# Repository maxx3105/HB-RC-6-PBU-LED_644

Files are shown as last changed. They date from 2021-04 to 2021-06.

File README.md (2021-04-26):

# HB-RC-6-PBU-LED_644
6-Fach Wandtaster mit Signal-Led auf Basis der AskSin++ für Homematic

Dieses Projekt basiert auf der Arbeit von [pa-pa](https://github.com/pa-pa/AskSinPP) ,[Jérôme](https://github.com/jp112sdl/Beispiel_AskSinPP).

# Hardware

### Bauteile

Bauteile                   | Bezeichnung          | Anzahl | Kommentar   | 
-------------------------- | -------------------- | ------ | ----------- | 
R1,R2                      | 240 Ohm              |   2    |             |
R3,R4                      | 10K Ohm              |   2    |             |
R5                         | 1K  Ohm              |   1    |             |
R6                         | 100K Ohm             |   1    |             |
C1, ..., C10               | 100n                 |   10   |             |
SW1, ..., SW7              | Taster               |   7    |             |
U1                         | Atmega 644P-AU       |   1    |             |
U2                         | CC1101               |   1    |             |
U3                         | SN74LVC1T45DBV       |   1    |             |
Q1                         | IRLML9301            |   1    |             |
D1                         | SMD Led 0805 Rot     |   1    |             |
D2                         | SMD Led 0805 Grün    |   1    |             |
D3,...,D8                  | SK6812 Mini          |   6    |             |
D9,...,D14                 | WS2812-2020          |   6    | Alternative |

Reichelt Liste comeing soon

#### Sonstiges

CC1101 https://de.aliexpress.com/item/32924239954.html

Taster https://de.aliexpress.com/item/32660690016.html?spm=a2g0s.9042311.0.0.27424c4dqj9wVN

~8,3 cm Draht als Antenne

### Programmieradapter

- 1x FTDI Programmer https://www.az-delivery.de/products/ftdi-adapter-ft232rl
- 1x ISP Programmer https://www.diamex.de/dxshop/USB-ISP-Programmer-fuer-Atmel-AVR

# Software

https://www.arduino.cc/en/software

### Firmware

Sketch https://github.com/jp112sdl/HB-RC-6-PBU-LED/blob/master/HB-RC-6-PBU-LED.ino

# Bauanleitung

coming soon

# Bilder
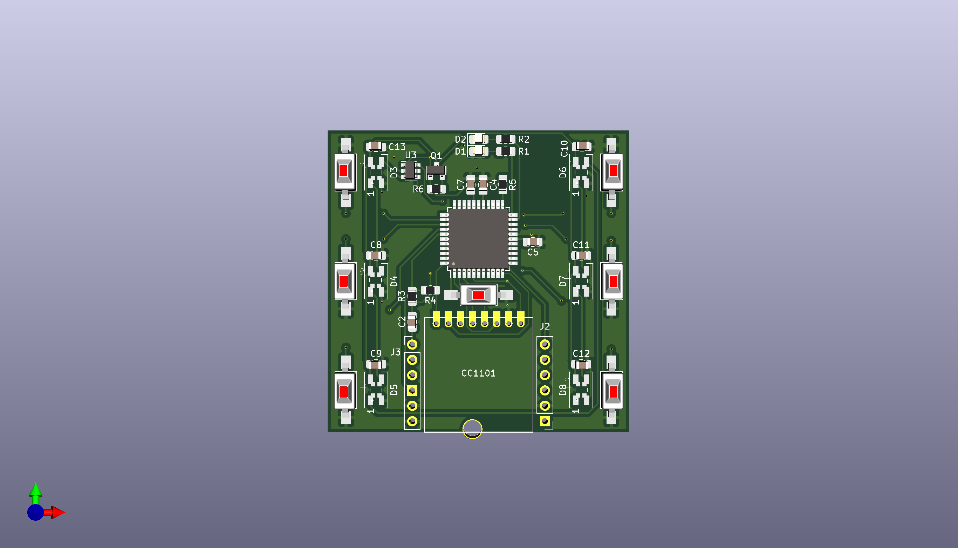
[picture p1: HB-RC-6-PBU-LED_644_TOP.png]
Vorderseite

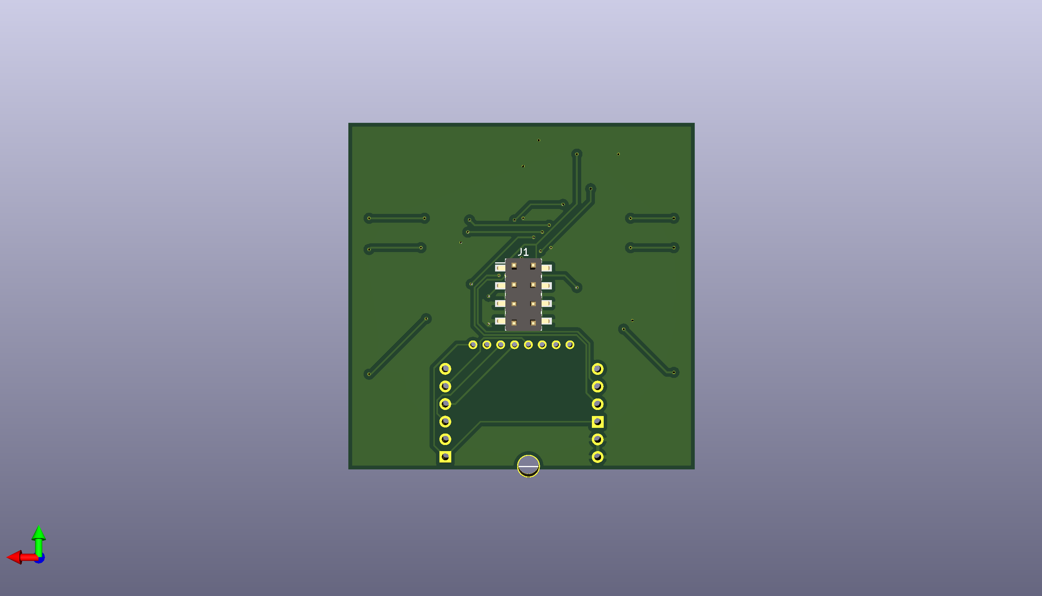
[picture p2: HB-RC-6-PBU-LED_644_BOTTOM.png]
Rückseite


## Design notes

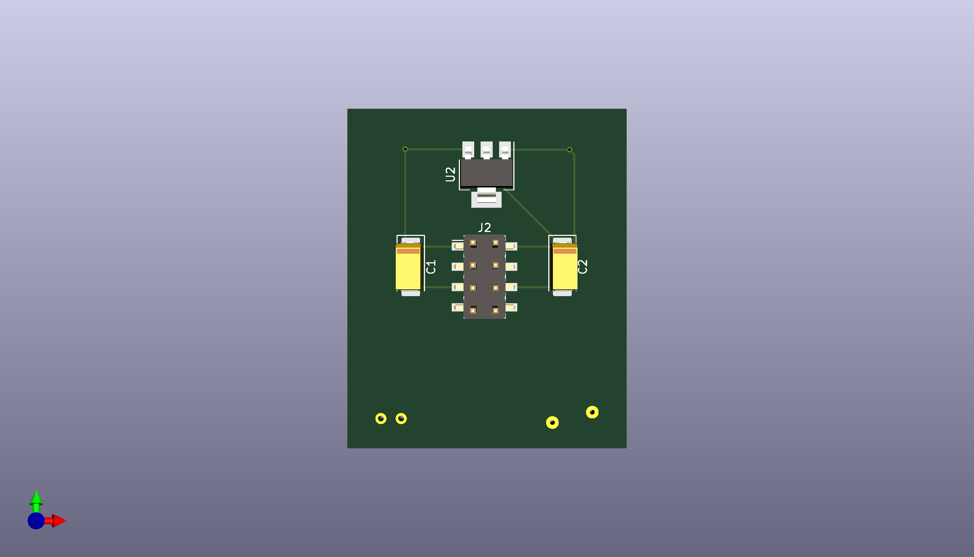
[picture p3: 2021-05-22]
Netzteil/Netzteil_Bottom.png

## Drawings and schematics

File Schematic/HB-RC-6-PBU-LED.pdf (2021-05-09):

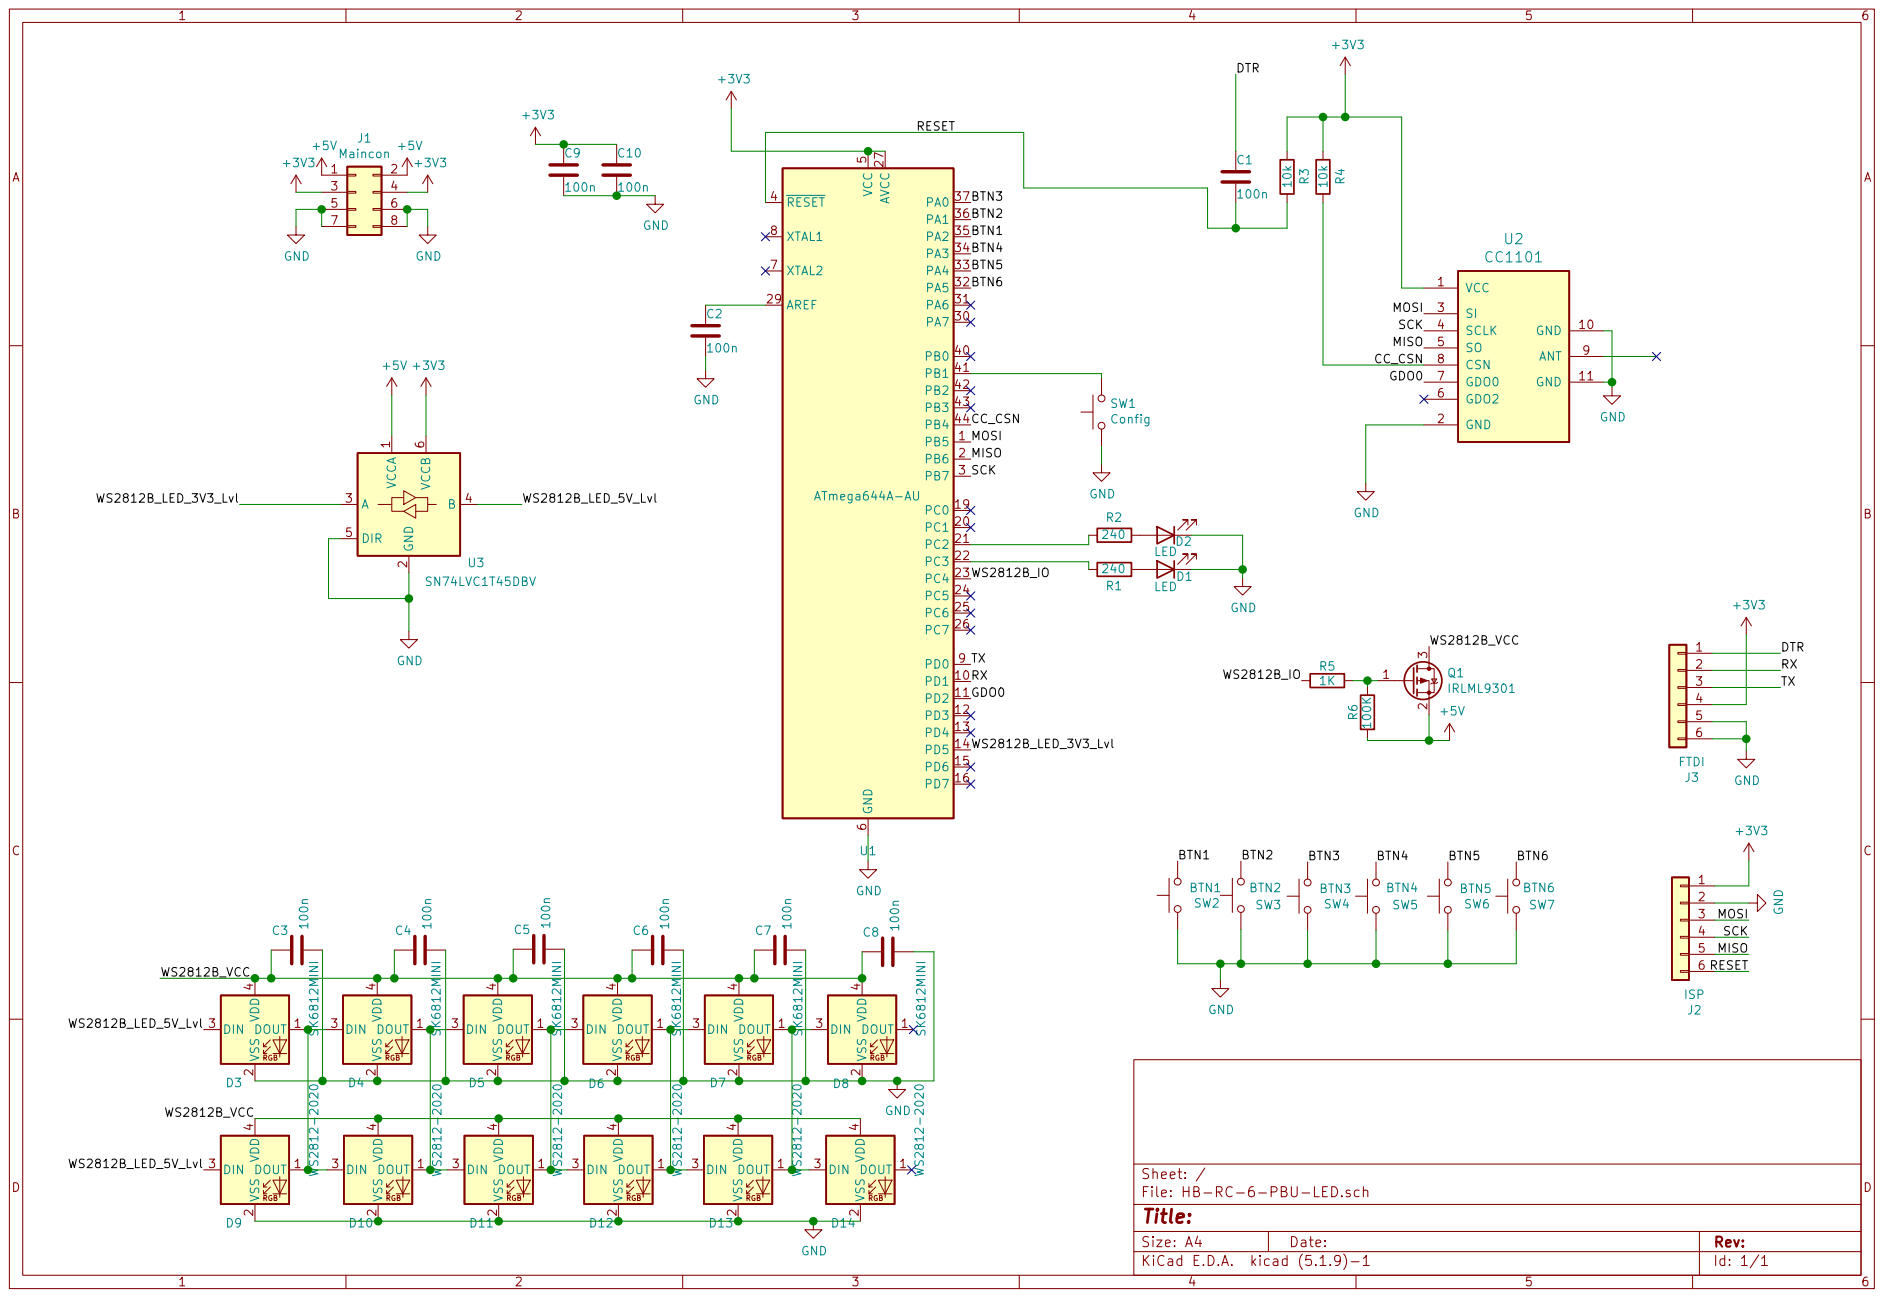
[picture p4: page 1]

Id: 1/1 Title: File: HB-RC-6-PBU-LED.sch Sheet: /

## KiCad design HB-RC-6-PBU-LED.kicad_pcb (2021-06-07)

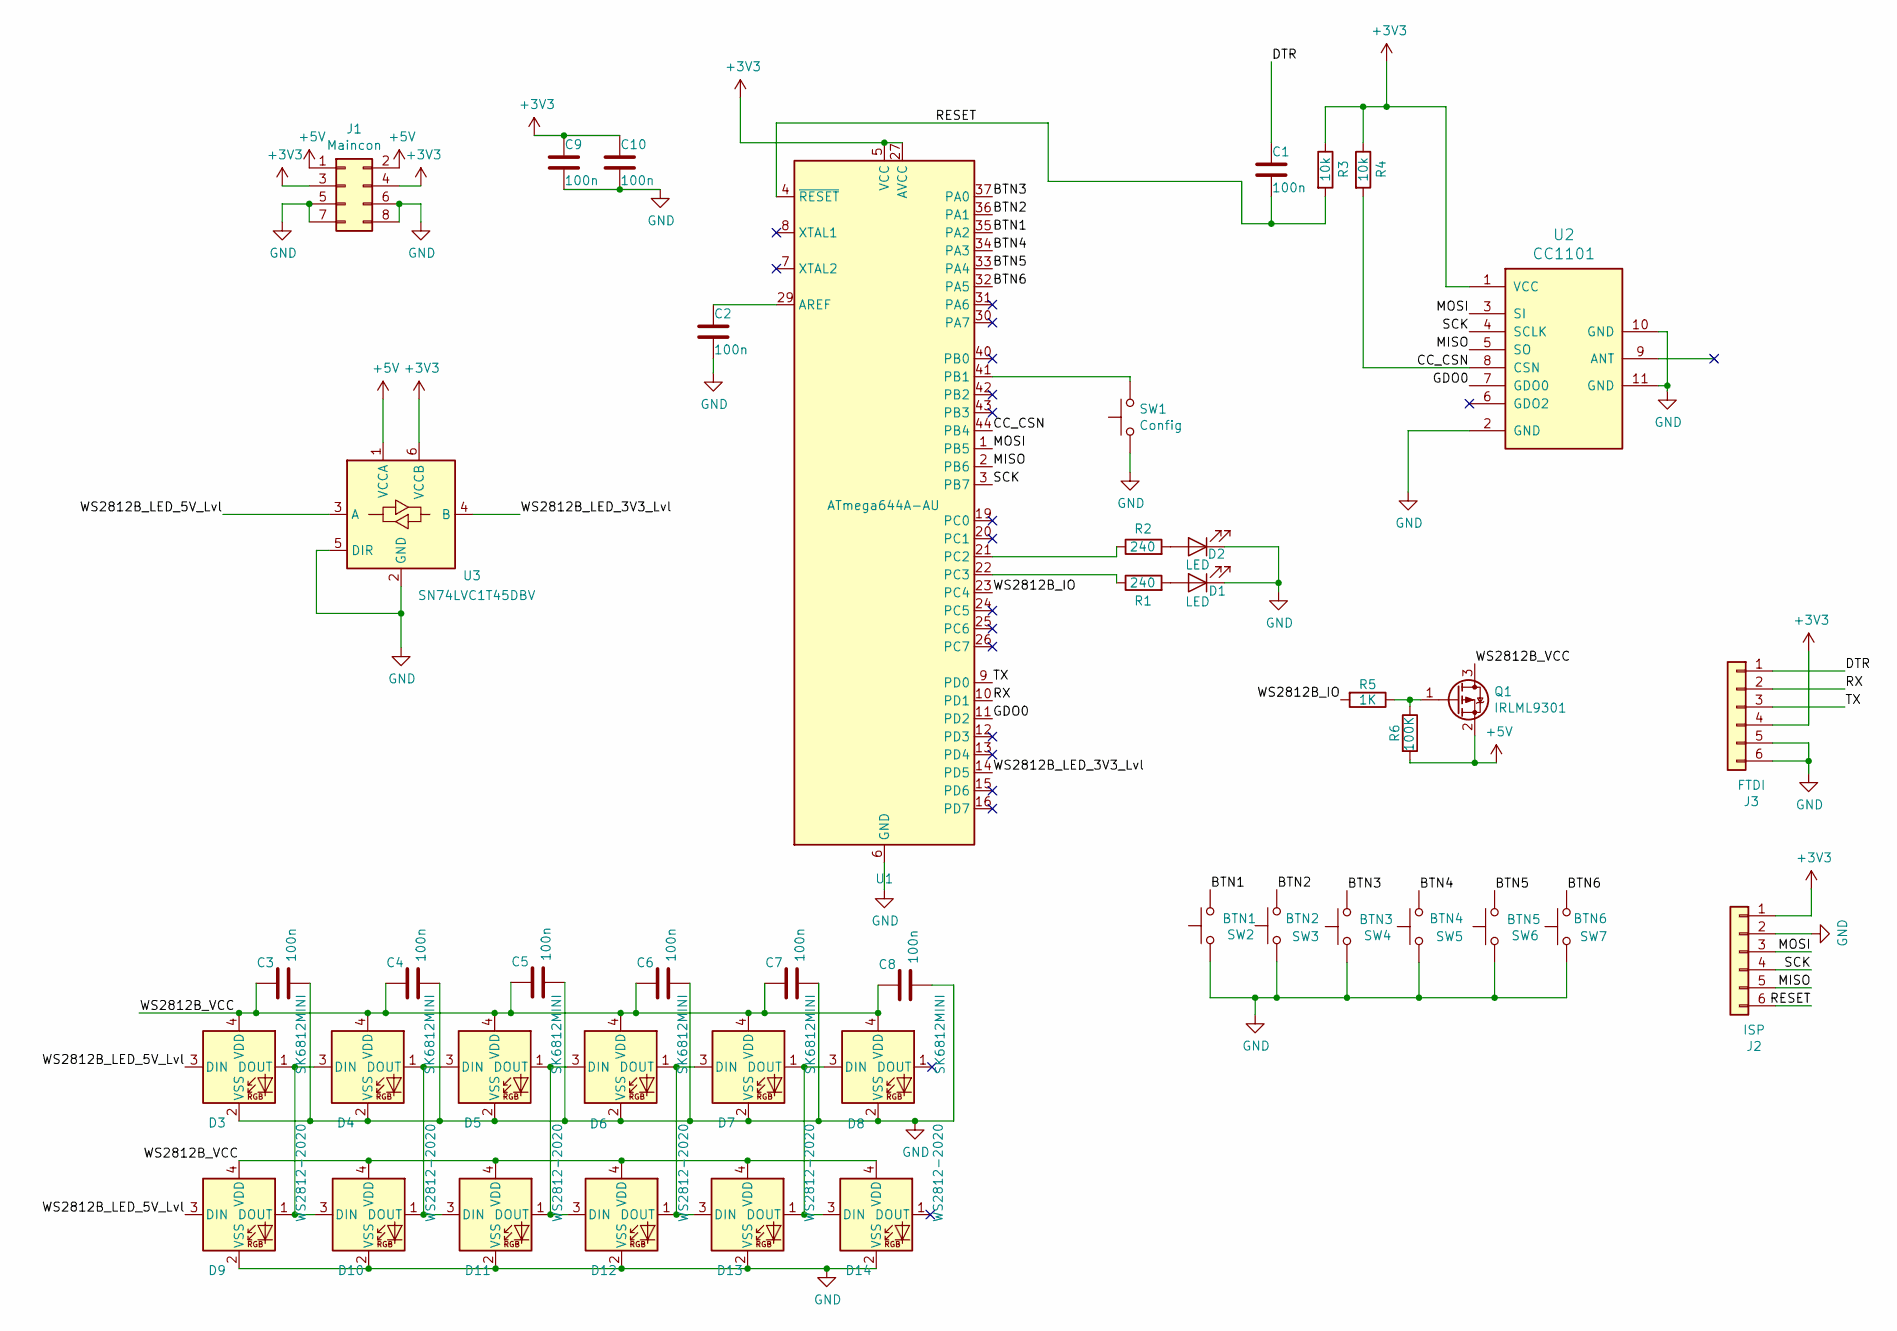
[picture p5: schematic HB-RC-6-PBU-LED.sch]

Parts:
C1, C2, C3, C4, C5, C6, C7, C8, C9, C10: 100n; C_0805_2012Metric_Pad1.18x1.45mm_HandSolder
D1, D2: LED; LED_0805_2012Metric_Pad1.15x1.40mm_HandSolder
D3, D4, D5, D6, D7, D8: SK6812MINI; LED_SK6812MINI_PLCC4_3.5x3.5mm_P1.75mm
D9, D10, D11, D12, D13, D14: WS2812-2020; LED_WS2812-2020
J1: Maincon; PinHeader_2x04_P2.54mm_Vertical_SMD
J2: ISP; PinHeader_1x06_P2.54mm_Vertical
J3: FTDI; PinHeader_1x06_P2.54mm_Vertical
Q1: IRLML9301; SOT-23
R1, R2: 240; R_0805_2012Metric_Pad1.20x1.40mm_HandSolder
R3, R4: 10k; R_0805_2012Metric_Pad1.20x1.40mm_HandSolder
R5: 1K; R_0805_2012Metric_Pad1.20x1.40mm_HandSolder
R6: 100K; R_0805_2012Metric_Pad1.20x1.40mm_HandSolder
SW1: Config; SW_SPST_FSMSM
SW2: BTN1; SW_SPST_FSMSM
SW3: BTN2; SW_SPST_FSMSM
SW4: BTN3; SW_SPST_FSMSM
SW5: BTN4; SW_SPST_FSMSM
SW6: BTN5; SW_SPST_FSMSM
SW7: BTN6; SW_SPST_FSMSM
U1: ATmega644A-AU; TQFP-44_10x10mm_P0.8mm
U2: CC1101; CC1101_SMD_THT
U3: SN74LVC1T45DBV; SOT-23-6

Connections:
+3V3: C9.1, C10.1, J1.3, J1.4, J2.1, J3.4, R3.1, R4.1, U1.5 (VCC), U1.17 (VCC), U1.27 (AVCC), U1.38 (VCC), U2.1 (VCC), U3.6 (VCCB)
+5V: J1.1, J1.2, Q1.2 (S), R6.2, U3.1 (VCCA)
/BTN1: SW2.2, U1.35 (PA2)
/BTN2: SW3.2, U1.36 (PA1)
/BTN3: SW4.2, U1.37 (PA0)
/BTN4: SW5.2, U1.34 (PA3)
/BTN5: SW6.2, U1.33 (PA4)
/BTN6: SW7.2, U1.32 (PA5)
/CC_CSN: R4.2, U1.44 (PB4), U2.8 (CSN)
/DTR: C1.1, J3.1
/GDO0: U1.11 (PD2), U2.7 (GDO0)
/MISO: J2.5, U1.2 (PB6), U2.5 (SO)
/MOSI: J2.3, U1.1 (PB5), U2.3 (SI)
/RESET: C1.2, J2.6, R3.2, U1.4 (~RESET)
/RX: J3.2, U1.10 (PD1)
/SCK: J2.4, U1.3 (PB7), U2.4 (SCLK)
/TX: J3.3, U1.9 (PD0)
/WS2812B_IO: R5.2, U1.23 (PC4)
/WS2812B_LED_3V3_Lvl: U1.14 (PD5), U3.4 (B)
/WS2812B_LED_5V_Lvl: D3.3 (DIN), D9.3 (DIN), U3.3 (A)
/WS2812B_VCC: C3.2, C4.2, C5.2, C6.2, C7.2, C8.2, D3.4 (VDD), D4.4 (VDD), D5.4 (VDD), D6.4 (VDD), D7.4 (VDD), D8.4 (VDD), D9.4 (VDD), D10.4 (VDD), D11.4 (VDD), D12.4 (VDD), D13.4 (VDD), D14.4 (VDD), Q1.3 (D)
GND: C2.2, C3.1, C4.1, C5.1, C6.1, C7.1, C8.1, C9.2, C10.2, D1.1 (K), D2.1 (K), D3.2 (VSS), D4.2 (VSS), D5.2 (VSS), D6.2 (VSS), D7.2 (VSS), D8.2 (VSS), D9.2 (VSS), D10.2 (VSS), D11.2 (VSS), D12.2 (VSS), D13.2 (VSS), D14.2 (VSS), J1.5, J1.6, J1.7, J1.8, J2.2, J3.5, J3.6, SW1.1, SW2.1, SW3.1, SW4.1, SW5.1, SW6.1, SW7.1, U1.6 (GND), U1.18 (GND), U1.28 (GND), U1.39 (GND), U2.2 (GND), U2.10 (GND), U2.11 (GND), U3.2 (GND), U3.5 (DIR)
unnamed: C2.1, U1.29 (AREF)
unnamed: D1.2 (A), R1.2
unnamed: D2.2 (A), R2.2
unnamed: D4.1 (DOUT), D5.3 (DIN), D10.1 (DOUT), D11.3 (DIN)
unnamed: D3.1 (DOUT), D4.3 (DIN), D9.1 (DOUT), D10.3 (DIN)
unnamed: D5.1 (DOUT), D6.3 (DIN), D11.1 (DOUT), D12.3 (DIN)
unnamed: D6.1 (DOUT), D7.3 (DIN), D12.1 (DOUT), D13.3 (DIN)
unnamed: D7.1 (DOUT), D8.3 (DIN), D13.1 (DOUT), D14.3 (DIN)
unnamed: Q1.1 (G), R5.1, R6.1
unnamed: R1.1, U1.22 (PC3)
unnamed: R2.1, U1.21 (PC2)
unnamed: SW1.2, U1.41 (PB1)

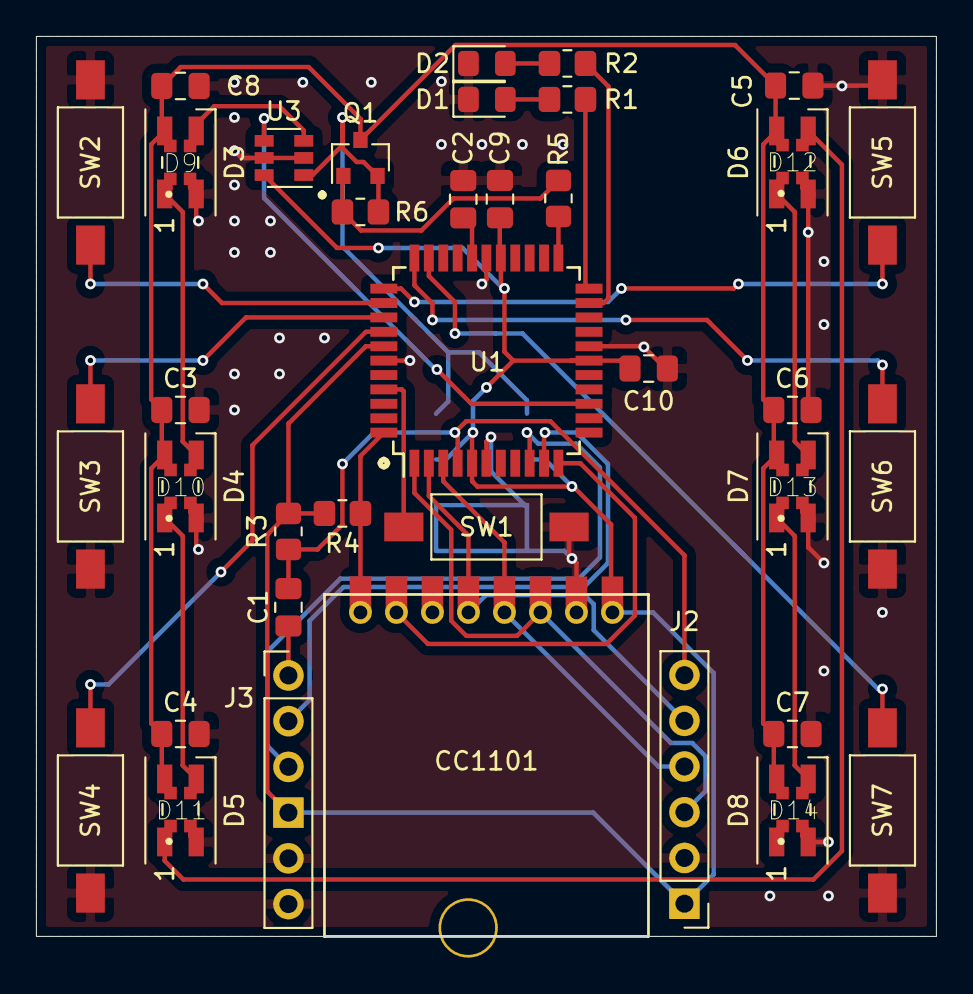
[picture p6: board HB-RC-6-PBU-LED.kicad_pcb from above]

Board: 2 copper layers, 50.0 x 50.0 mm, 44 parts (1 on the bottom side), 34 nets.

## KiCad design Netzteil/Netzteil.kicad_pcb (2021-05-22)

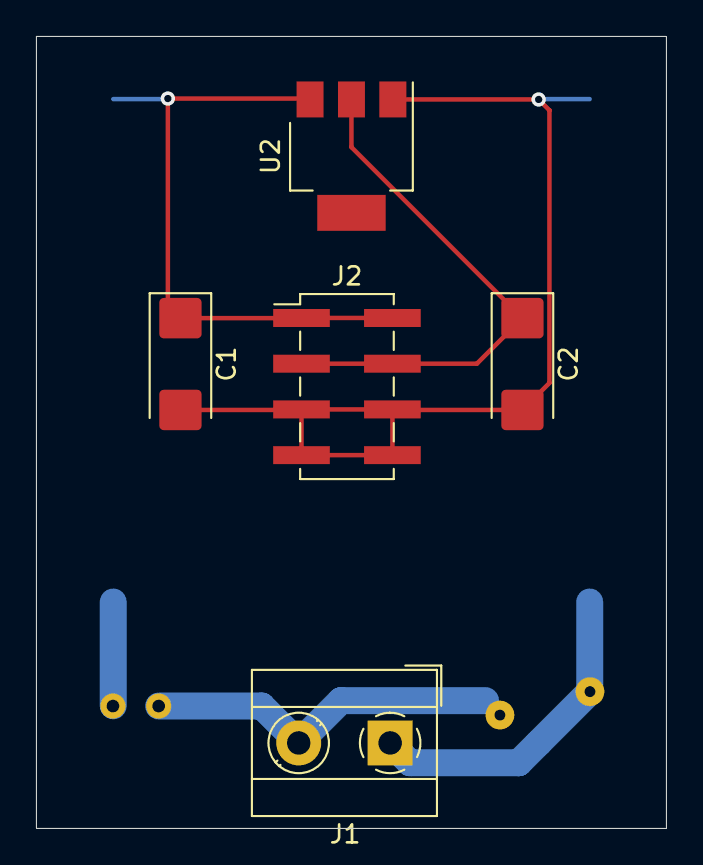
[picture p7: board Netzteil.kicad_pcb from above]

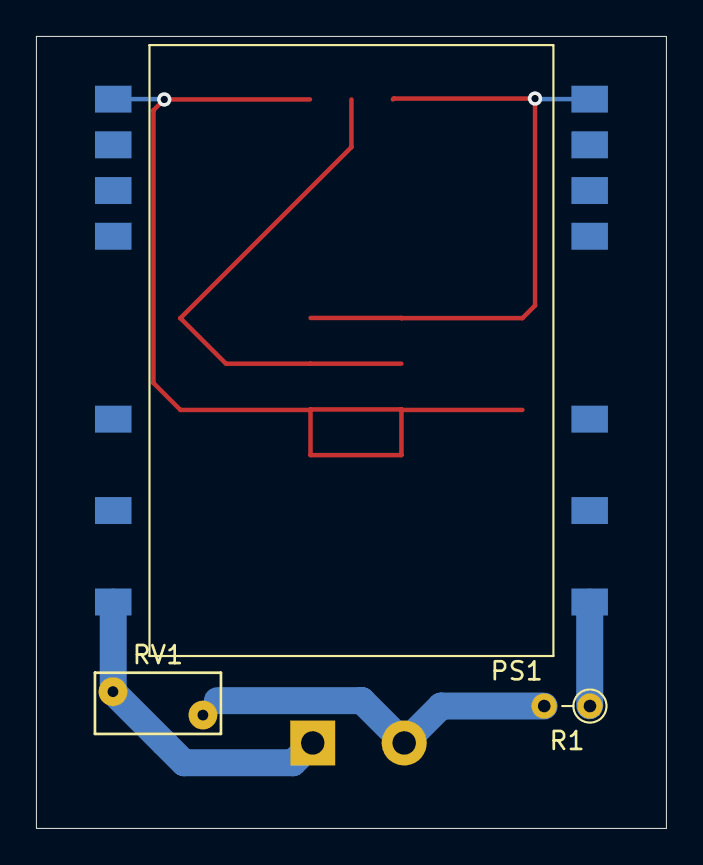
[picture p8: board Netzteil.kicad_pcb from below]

Board: 2 copper layers, 35.0 x 44.0 mm, 8 parts (3 on the bottom side), 6 nets.

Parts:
C1, C2: 10µ; CP_EIA-6032-28_Kemet-C_Pad2.25x2.35mm_HandSolder
J1: Screw_Terminal_01x02; TerminalBlock_MetzConnect_Type101_RT01602HBWC_1x02_P5.08mm_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
J2: Conn_02x04_Odd_Even; PinHeader_2x04_P2.54mm_Vertical_SMD
PS1: IRM-02-5S; Converter_ACDC_MeanWell_IRM-02-xx_SMD
R1: 1K; R_Axial_DIN0204_L3.6mm_D1.6mm_P2.54mm_Vertical
RV1: Varistor; RV_Disc_D7mm_W3.4mm_P5mm
U2: TLV1117-33; SOT-223

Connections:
+3V3: C2.1, J2.3, J2.4, U2.2
+5V: C1.1, J2.1, J2.2, PS1.12, U2.3
GND: C1.2, C2.2, J2.5, J2.6, J2.7, J2.8, PS1.13, U2.1
unnamed: J1.1, PS1.24, RV1.2
unnamed: J1.2, R1.2, RV1.1
unnamed: PS1.1, R1.1

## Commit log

2021-05-22 Add files via upload
    bugfix
    [HB-RC-6-PBU-LED-B_Cu.gbr, HB-RC-6-PBU-LED-B_Mask.gbr, HB-RC-6-PBU-LED-B_Paste.gbr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]
2021-06-07 Bugfix on Transceiver PIN A B
    [HB-RC-6-PBU-LED-B_Cu.gbr, HB-RC-6-PBU-LED-B_Mask.gbr, HB-RC-6-PBU-LED-B_Paste.gbr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]
